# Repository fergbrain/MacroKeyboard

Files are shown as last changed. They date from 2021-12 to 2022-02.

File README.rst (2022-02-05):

.. |ss| raw:: html

    <strike>

.. |se| raw:: html

    </strike>
******
README
******

This is the first successful PCB I've designed. I made it as part of `TeachMePCB's <https://www.teachmepcb.com>`_ PCB Layout 101 class.

Everyone in the course made a macrokeypad of some sort. The core "requirements" were:

* 10 MX-style key switches
* 2 Rotary Encoders with RGB leds
* VEML7700 Ambient Light Sensor (I2C)
* NLSF595 LED Driver (SPI)
* 10 NeoPixel lights (1-wire)
* Don't make a rectangular PCB
* Raspberry Pi Pico microcontroller

I made a couple of changes:

* Swapped PCA9745B for NLSF595
* Added ePaper display (because why not make my first project harder)

Required Libraries
==================
* Standard CircuitPython
* Adafruit CircuitPython Library
    * adafruit_hid
    * adafruit_led_animation
    * adafruit_debouncer
    * adafruit_veml7700
    * adafruit_display_text
    * adafruit_button
* `fergcorp_pca9745b <https://github.com/fergbrain/Fergcorp_CircuitPython_PCA9745B>`_
* `fergcorp_pdispectra <https://github.com/fergbrain/Fergcorp_CircuitPython_PDISpectra>`_

Build Notes and Errata:
=======================
For P/N 21-11.03-3, Rev NEW
---------------------------
**Last updated: 2 Feb 2022**

R1 (c5022a6)
^^^^^^^^^^^^

U401 (PI4ULS5V201TAEX), Pin 6:

* IS: Connected to ground.
* SHOULD BE: Connected to 5V+ via a 4.7K ohm resistor

*Note: All annotations on the PCB were also reset and reassigned. However, the original annotation designations are used in this document.*

R2 (fcf9d7e)
^^^^^^^^^^^^
R2404, Pin 03 (SPI_MISO) of U2701 (PCA9745BTWJ)

* IS: Connected to SPI_MISO via R2704 (1k ohm)
* SHOULD BE: No resistor

Pin 27 (SPI_MOSI) of U2701 (PCA9745BTWJ)

* IS: Connected to SPI_MOSI via R2706 (1k ohm)
* SHOULD BE: No resistor

R2707, Pin 26 (SPI_SCLK) of U2701 (PCA9745BTWJ)

* IS: Connected to SPI_SCLK via R2707 (1k ohm)
* SHOULD BE: No resistor

R3 (bb8617a)
^^^^^^^^^^^^
S3001 (Rotary Encoder)

* IS: Pin 01 (red LED) and Pin 04 (blue LED) are swapped
    * S3001 Pin 01 (red LED) goes to U2701 Pin 13 (blue LED)
    * S3001 Pin 04 (blue LED) goes to U2701 Pin 11 (red LED)

* SHOULD BE:

    * S3001 Pin 01 (red LED) connects to 2701 Pin 11 (red LED)
    * S3001 Pin 04 (blue LED) to U2701 Pin 13 (blue LED)

*Note: This has been fixed in software for this version of the PCB*

R4 (3040ea1)
^^^^^^^^^^^^
J2901 (Connector for epaper) Pin 11 (Data/Command) and Pin 09 (Busy)

* IS:

    * U2801 Pin 15 labeled as GPIO12 and connects to J2901 Pin 11
    * U2801 Pin 16 is labeled as GPIO11 and connects to J2901 Pin 09

* SHOULD BE:

    * U2801 Pin 15 labeled as GPIO11 and connects to Pin 09
    * U2801 Pin 16 labeled as GPIO12 and connects to Pin 11

*Note: This has been fixed in software for this version of the PCB*

R5 (51e2212 / 8b634cf)
^^^^^^^^^^^^
* IS: R2901 is 470 ohms
* SHOULD BE: R2901 is 0.47 ohms

|ss| R6 (196a722) |se|
^^^^^^^^^^^^
* |ss|IS: J2901 (Connector for epaper) Pin 10 (Reset) connected to +3.3V via R2902 (100k ohm)|se|
* |ss|SHOULD BE: J2901 Pin 10 connected to U2801 Pin 14 (GPIO10)|se|
|ss|
*Note: This results in SWITCH 4 and ePaper Reset sharing a pin because there are no other pins available. The primary result is that careful context switching needs to managed in software to:*

1.	Deinitialize GPIO10 as an input for SWITCH 4
2.	Setup the ePaper display interface (which uses GPIO10 as an output)
3.	Perform whatever ePaper update is needed
4.	Deinitialze the ePaper interface (which deinitializes GPIO10 as an output)
5.	Re-initialize GPIO10 as an input for SWITCH 4

*Also, while the ePaper is not enabled (i.e. not initialized/reinitialized), GPIO17 (ePaper CS) needs to be set HIGH to prevent the ePaper controller from thinking that data on the SPI line is intended for it.*
|se|

R7 (80c609b)
^^^^^^^^^^^^
* IS: J2901 is Molex P/N 5052782433
* SHOULD BE: J2901 is Amphenol P/N F31L-1A7H1-11024

* IS: Component S201 and S3001 is SparkFun P/N COM-15141
* SHOULD BE: Bournes P/N PEL12T-4225S-S1024

*Note: COM-15141 was originally sourced as an alternate since the Bournes parts weren’t avaible. However, COM-15141 has quality control issues, including the Red LED not working well and the rotary action not registering correctly. SparkFun is aware of these issues.*

R8 (2cafc4d)
^^^^^^^^^^^^
* IS: J2901 (Connector for epaper) Pin 10 (Reset) connected to +3.3V via R2902 (100k ohm)
* SHOULD BE: J2901 Pin 10 connected to U2801 Pin 48 (GPIO25_LED aka TP5)

*Note: This replaces R6 in its entirety.*

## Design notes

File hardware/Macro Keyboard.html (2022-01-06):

# /Users/andrewferguson/Documents/10-19 Projects/11 Design/11.03 TeachMePCB/Macro Keyboard/Macro Keyboard.sch

Wednesday, December 29, 2021 at 08:03:08 PM

Eeschema (5.1.12-1-10_14)

Component Count:126

Ref | Qnty | Value | Part | Footprint | Description | Vendor
C201, C202, C203, C401, C402, C601, C701, C801, C901, C1001, C1101, C1201, C1301, C1401, C1501, C2701, C2801, C2802, C2901, C2903, C2904, C2905, C2906, C2907, C2908, C2909, C3001, C3002, C3003 | 29 | 1 uF 10% 10V | Device:C_Small | Capacitor_SMD:C_0805_2012Metric_Pad1.18x1.45mm_HandSolder | Unpolarized capacitor, small symbol
C301, C1701, C1801, C1901, C2001, C2101, C2201, C2301, C2401, C2501, C2601 | 11 | 10 uF 10% 10V | Device:C_Small | Capacitor_SMD:C_0805_2012Metric_Pad1.18x1.45mm_HandSolder | Unpolarized capacitor, small symbol
C2902 | 1 | 4.7 uF 10% 10V | Device:C_Small | Capacitor_SMD:C_0805_2012Metric_Pad1.18x1.45mm_HandSolder | Unpolarized capacitor, small symbol
D1701, D1801, D1901, D2001, D2101, D2201, D2301, D2401, D2501, D2601 | 10 | SK6812MINI-E | Macro_Keyboard:SK6812MINI-E | Macro Keyboard:MX_SK6812MINI-E_REV
D2901, D2902, D2903 | 3 | MBR0530 | Device:D_Schottky_Small | Diode_SMD:D_SOD-123 | Schottky diode, small symbol
J2901 | 1 | FPC 1x24 | Macro_Keyboard:Conn_01x24 | Macro Keyboard:Amphenol_F31L-1A7H1-11024 | Generic connector, single row, 01x24, script generated (kicad-library-utils/schlib/autogen/connector/)
L2901 | 1 | 10 uH 20% 0.8A | Device:L_Small | Inductor_SMD:L_Taiyo-Yuden_NR-40xx_HandSoldering | Inductor, small symbol
Q2901 | 1 | Q_PJFET_GDS | Device:Q_PJFET_GDS | Package_TO_SOT_SMD:SOT-23 | P-JFET transistor, gate/drain/source
R201, R203, R207, R301, R302, R601, R701, R801, R901, R1001, R1101, R1201, R1301, R1401, R1501, R2701, R2801, R3001, R3003, R3007 | 20 | 4.7k 5% | Device:R_Small_US | Resistor_SMD:R_0805_2012Metric_Pad1.20x1.40mm_HandSolder | Resistor, small US symbol
R202, R204, R602, R702, R802, R902, R1002, R1102, R1202, R1302, R1402, R1502, R3002, R3004 | 14 | 47k 5% | Device:R_Small_US | Resistor_SMD:R_0805_2012Metric_Pad1.20x1.40mm_HandSolder | Resistor, small US symbol
R205, R1601, R3005 | 3 | 150 5% | Device:R_Small_US | Resistor_SMD:R_0805_2012Metric_Pad1.20x1.40mm_HandSolder | Resistor, small US symbol
R206, R1602, R3006 | 3 | 2.7k 5% | Device:R_Small_US | Resistor_SMD:R_0805_2012Metric_Pad1.20x1.40mm_HandSolder | Resistor, small US symbol
R208, R209, R3008, R3009 | 4 | 68 5% | Device:R_Small_US | Resistor_SMD:R_0805_2012Metric_Pad1.20x1.40mm_HandSolder | Resistor, small US symbol
R2702, R2703, R2704, R2706, R2707 | 5 | 1k 5% | Device:R_Small_US | Resistor_SMD:R_0805_2012Metric_Pad1.20x1.40mm_HandSolder | Resistor, small US symbol
R2705, R2902 | 2 | 100k 5% | Device:R_Small_US | Resistor_SMD:R_0805_2012Metric_Pad1.20x1.40mm_HandSolder | Resistor, small US symbol
R2901 | 1 | 470 5% | Device:R_Small_US | Resistor_SMD:R_0805_2012Metric_Pad1.20x1.40mm_HandSolder | Resistor, small US symbol
S201, S3001 | 2 | ENCODER-RGB-SWITCH | TMPCB_R2:ENCODER-RGB-SWITCH | ENCODER_LED_3
SW601, SW701, SW801, SW901, SW1001, SW1101, SW1201, SW1301, SW1401, SW1501 | 10 | KH-PS1611-54 | Switch:SW_Push | TMPPCB_R2:SW_MX | Push button switch, generic, two pins
SW2801 | 1 | SWITCH TACTILE SPST-NO 50MA 12V | Switch:SW_Push | Button_Switch_SMD:SW_SPST_TL3305A | Push button switch, generic, two pins
U301 | 1 | VEML7700 | TMPCB_R2:VEML7700 | TMPPCB_R2:SMD4-X07Y16P127
U401 | 1 | PI4ULS5V201TAEX | TMPCB_R2:PI4ULS5V201TAEX | Package_TO_SOT_SMD:SOT-23-6
U2701 | 1 | PCA9745BTWJ | Macro_Keyboard:PCA9745BTWJ | Macro Keyboard:PCA9745BTWJ
U2801 | 1 | Pico-JER | TMPCB_R2:Pico-JER | TMPPCB_R2:RPi_Pico_SMD_TH-JER

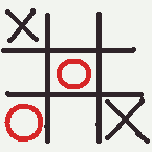
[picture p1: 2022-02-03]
tictactoe.bmp

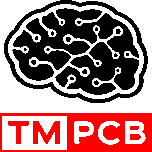
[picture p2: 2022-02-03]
tmpcb.bmp

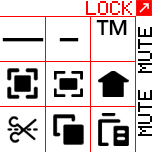
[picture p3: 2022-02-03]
macrokeyboard.bmp

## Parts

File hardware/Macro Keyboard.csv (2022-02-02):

Item | Qty | Reference(s) | Value | Digikey PN | MFG | MFG # | Notes
1 | 29 | C201, C202, C203, C401, C402, C601, C701, C801, C901, C1001, C1101, C1201, C1301, C1401, C1501, C2701, C2801, C2802, C2901, C2903, C2904, C2905, C2906, C2907, C2908, C2909, C3001, C3002, C3003 | 1 uF 10% 10V | 1276-1275-1-ND | Samsung Electro-Mechanics | CL21B105KPFNNNE
2 | 11 | C301, C1701, C1801, C1901, C2001, C2101, C2201, C2301, C2401, C2501, C2601 | 10 uF 10% 10V | 1276-2402-1-ND | Samsung Electro-Mechanics | CL21A106KPCLQNC
3 | 1 | C2902 | 4.7 uF 10% 10V | 1276-1259-1-ND | Samsung Electro-Mechanics | CL21A475KPFNNNE
4 | 10 | D1701, D1801, D1901, D2001, D2101, D2201, D2301, D2401, D2501, D2601 | SK6812MINI-E | 1528-4960-ND | Adafruit Industries LLC | 4960 | Comes in pack of 10
5 | 3 | D2901, D2902, D2903 | MBR0530 | MBR0530TPMSCT-ND | Micro Commercial Co | MBR0530-TP
6 | 1 | J2901 | FPC 1x24 | WM20872CT-ND | Molex | 5052782433
7 | 1 | L2901 | 10 uH 20% 0.8A | 587-1659-1-ND | Taiyo Yuden | NR4012T100M
8 | 1 | Q2901 | Q_PJFET_GDS | TSM850N06CXRFGCT-ND | Taiwan Semiconductor Corporation | TSM850N06CX RFG
9 | 20 | R201, R203, R207, R301, R302, R601, R701, R801, R901, R1001, R1101, R1201, R1301, R1401, R1501, R2701, R2801, R3001, R3003, R3007 | 4.7k 5% | RMCF0805JT4K70CT-ND | Stackpole Electronics Inc | RMCF0805JT4K70
10 | 14 | R202, R204, R602, R702, R802, R902, R1002, R1102, R1202, R1302, R1402, R1502, R3002, R3004 | 47k 5% | RMCF0805JT47K0CT-ND | Stackpole Electronics Inc | RMCF0805JT47K0
11 | 3 | R205, R1601, R3005 | 150 5% | RMCF0805JT150RCT-ND | Stackpole Electronics Inc | RMCF0805JT150R
12 | 3 | R206, R1602, R3006 | 2.7k 5% | RMCF0805JT2K70CT-ND | Stackpole Electronics Inc | RMCF0805JT2K70
13 | 4 | R208, R209, R3008, R3009 | 68 5% | RMCF0805JT68R0CT-ND | Stackpole Electronics Inc | RMCF0805JT68R0
14 | 5 | R2702, R2703, R2704, R2706, R2707 | 1k 5% | RMCF0805JT1K00CT-ND | Stackpole Electronics Inc | RMCF0805JT1K00
15 | 2 | R2705, R2902 | 100k 5% | RMCF0805JT100KCT-ND | Stackpole Electronics Inc | RMCF0805JT100K
16 | 1 | R2901 | 470 5% | RMCF0805JT470RCT-ND | Stackpole Electronics Inc | RMCF0805JT470R
17 | 2 | S201, S3001 | ENCODER-RGB- SWITCH | 1568-COM-15141-ND | SparkFun Electronics | COM-15141 | Ordered from Spark Fun directly
18 | 10 | SW601, SW701, SW801, SW901, SW1001, SW1101, SW1201, SW1301, SW1401, SW1501 | KH-PS1611-54 | 1528-495ND | Adafruit Industries LLC | 4955 | Comes in pack of 10
19 | 1 | SW2801 | SWITCH TACTILE SPST-NO 50MA 12V | EG5353CT-ND | E-Switch | TL3305AF260QG
20 | 1 | U301 | VEML7700 | VEML7700CT-ND | Vishay Semiconductor | VEML7700-TR
21 | 1 | U401 | PI4ULS5V201TAEX | PI4ULS5V201TAEXCT-ND | Diodes Inc | PI4ULS5V201TAEX
22 | 1 | U2701 | PCA9745BTWJ | 568-14156-1-ND | NXP USA Inc. | PCA9745BTWJ
23 | 1 | U2801 | Pico-JER | 2648-SC0915CT-ND | Raspberry Pi | SC0915
Source: |  |  | /Users/andrewferguson/Documents/10-19 Projects/11 Design/11.03 TeachMePCB/Macro Keyboard/Macro Keyboard.sch
Date: |  |  | Wednesday, December 29, 2021 at 08:10:08 PM
Tool: |  |  | Eeschema (5.1.12-1-10_14)
Generator: |  |  | /Applications/KiCad/kicad.app/Contents/SharedSupport/plugins/bom_csv_grouped_by_value.py
Component Count: |  |  | 126

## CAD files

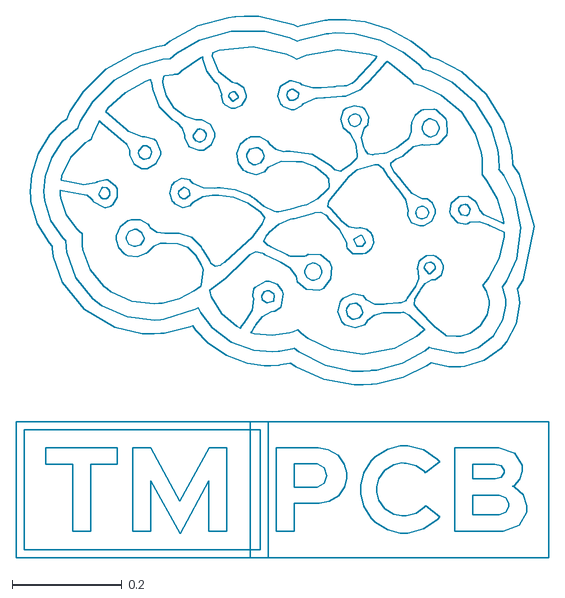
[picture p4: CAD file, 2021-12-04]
hardware/Asset 1.dxf
0.969 x 0.986

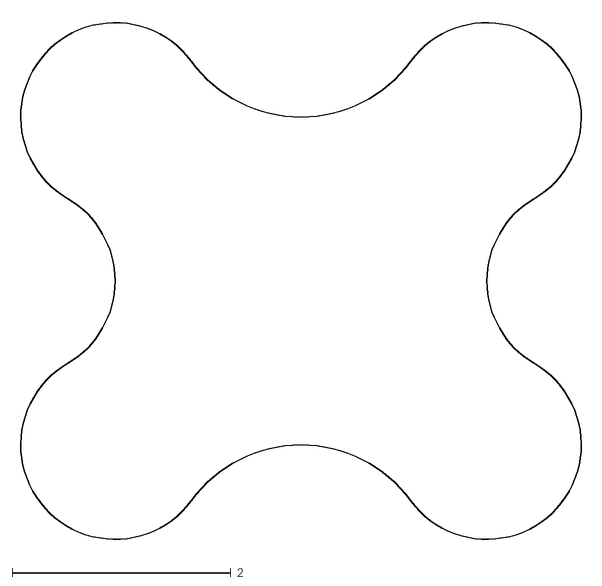
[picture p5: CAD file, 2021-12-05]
hardware/outline/SK6812E-Sketch.dxf
5.21 x 4.85

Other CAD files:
hardware/outline/SK6812E.FCStd
hardware/outline/Outline.FCStd
hardware/Asset-1.dxf
hardware/outline/Outline.dxf

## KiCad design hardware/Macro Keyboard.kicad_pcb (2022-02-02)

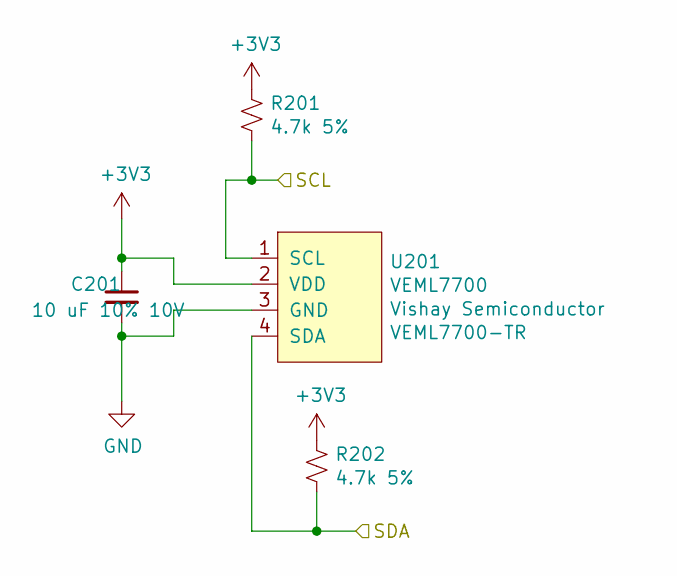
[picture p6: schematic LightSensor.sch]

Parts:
C201: 10 uF 10% 10V; C_0805_2012Metric_Pad1.18x1.45mm_HandSolder; MFG # CL21A106KPCLQNC; Digikey PN 1276-2402-1-ND
R201, R202: 4.7k 5%; R_0805_2012Metric_Pad1.20x1.40mm_HandSolder; MFG # RMCF0805JT4K70; Digikey PN RMCF0805JT4K70CT-ND
U201: VEML7700; SMD4-X07Y16P127; MFG # VEML7700-TR; Digikey PN VEML7700CT-ND

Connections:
+3V3: C201.1, R201.1, R202.1, U201.2 (VDD); also elsewhere on the board
/SCL: R201.2, U201.1 (SCL); also elsewhere on the board
/SDA: R202.2, U201.4 (SDA); also elsewhere on the board
GND: C201.2, U201.3 (GND); also elsewhere on the board

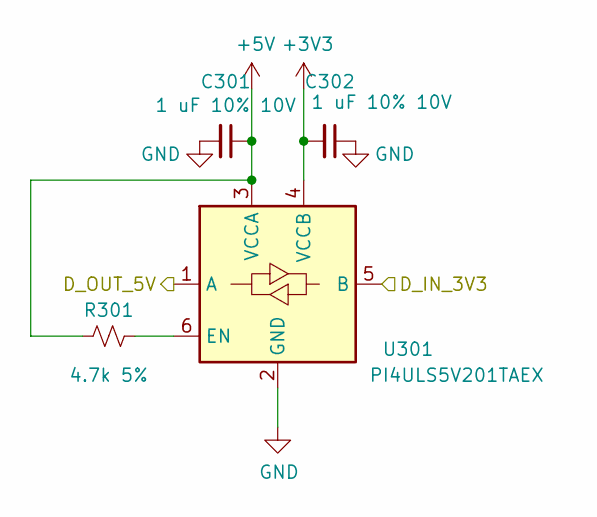
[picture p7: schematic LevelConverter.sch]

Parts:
C301, C302: 1 uF 10% 10V; C_0805_2012Metric_Pad1.18x1.45mm_HandSolder; MFG # CL21B105KPFNNNE; Digikey PN 1276-1275-1-ND
R301: 4.7k 5%; R_0805_2012Metric_Pad1.20x1.40mm_HandSolder
U301: PI4ULS5V201TAEX; SOT-23-6; MFG # PI4ULS5V201TAEX; Digikey PN PI4ULS5V201TAEXCT-ND

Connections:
+3V3: C302.2, U301.4 (VCCB); also elsewhere on the board
+5V: C301.1, R301.2, U301.3 (VCCA); also elsewhere on the board
/D_IN_3V3: U301.5 (B); also elsewhere on the board
/Level Converter/D_OUT_5V: U301.1 (A); also elsewhere on the board
GND: C301.2, C302.1, U301.2 (GND); also elsewhere on the board
unnamed: R301.1, U301.6 (EN)

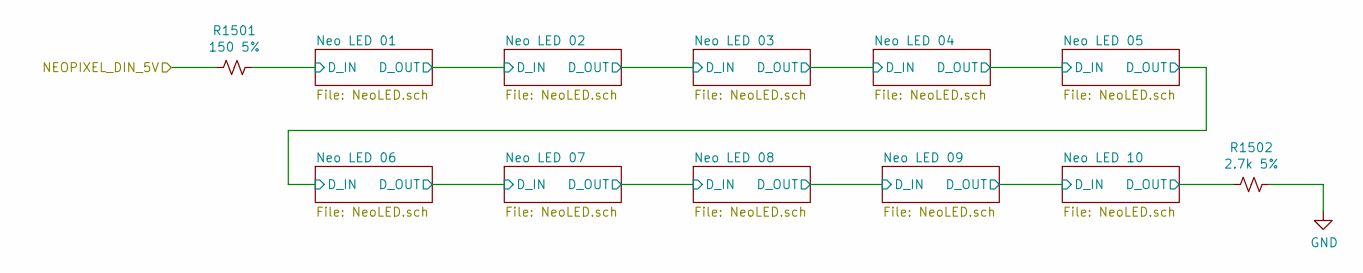
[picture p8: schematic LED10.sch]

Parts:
R1501: 150 5%; R_0805_2012Metric_Pad1.20x1.40mm_HandSolder; MFG # RMCF0805JT150R; Digikey PN RMCF0805JT150RCT-ND
R1502: 2.7k 5%; R_0805_2012Metric_Pad1.20x1.40mm_HandSolder; MFG # RMCF0805JT2K70; Digikey PN RMCF0805JT2K70CT-ND

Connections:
/LED 10/Neo LED 01/D_IN: R1501.1; also elsewhere on the board
/LED 10/Neo LED 10/D_OUT: R1502.2; also elsewhere on the board
/Level Converter/D_OUT_5V: R1501.2; also elsewhere on the board
GND: R1502.1; also elsewhere on the board

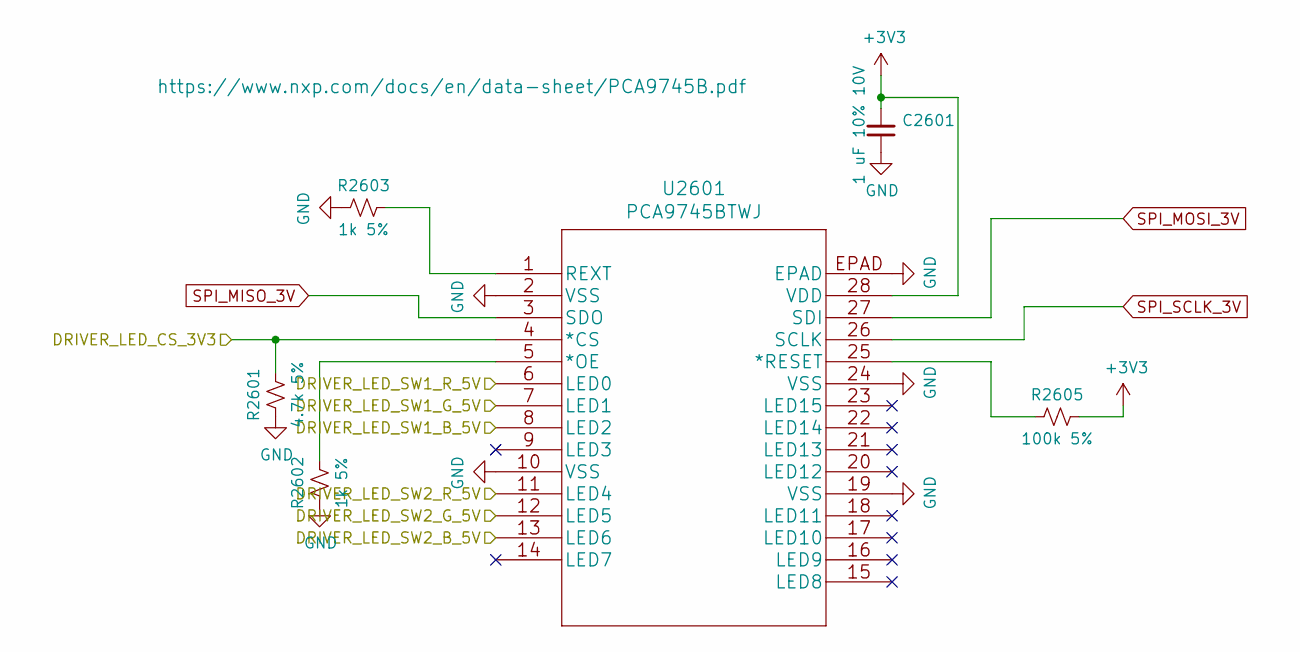
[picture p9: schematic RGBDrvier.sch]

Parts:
C2601: 1 uF 10% 10V; C_0805_2012Metric_Pad1.18x1.45mm_HandSolder; MFG # CL21B105KPFNNNE; Digikey PN 1276-1275-1-ND
R2601: 4.7k 5%; R_0805_2012Metric_Pad1.20x1.40mm_HandSolder; MFG # RMCF0805JT4K70; Digikey PN RMCF0805JT4K70CT-ND
R2602, R2603: 1k 5%; R_0805_2012Metric_Pad1.20x1.40mm_HandSolder; MFG # RMCF0805JT1K00; Digikey PN RMCF0805JT1K00CT-ND
R2605: 100k 5%; R_0805_2012Metric_Pad1.20x1.40mm_HandSolder; MFG # RMCF0805JT100K; Digikey PN RMCF0805JT100KCT-ND
U2601: PCA9745BTWJ; MFG # PCA9745BTWJ; Digikey PN 568-14156-1-ND

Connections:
+3V3: C2601.2, R2605.1, U2601.28 (VDD); also elsewhere on the board
/DRIVER_LED_CS: R2601.2, U2601.4 (*CS); also elsewhere on the board
/RGB Driver/DRIVER_LED_SW1_B_5V: U2601.8 (LED2); also elsewhere on the board
/RGB Driver/DRIVER_LED_SW1_G_5V: U2601.7 (LED1); also elsewhere on the board
/RGB Driver/DRIVER_LED_SW1_R_5V: U2601.6 (LED0); also elsewhere on the board
/RGB Driver/DRIVER_LED_SW2_B_5V: U2601.13 (LED6); also elsewhere on the board
/RGB Driver/DRIVER_LED_SW2_G_5V: U2601.12 (LED5); also elsewhere on the board
/RGB Driver/DRIVER_LED_SW2_R_5V: U2601.11 (LED4); also elsewhere on the board
GND: C2601.1, R2601.1, R2602.1, R2603.2, U2601.2 (VSS), U2601.10 (VSS), U2601.19 (VSS), U2601.24 (VSS), U2601.EPAD; also elsewhere on the board
unnamed: R2602.2, U2601.5 (*OE)
unnamed: R2603.1, U2601.1 (REXT)
unnamed: R2605.2, U2601.25 (*RESET)
SPI_MISO_3V: U2601.3 (SDO); also elsewhere on the board
SPI_MOSI_3V: U2601.27 (SDI); also elsewhere on the board
SPI_SCLK_3V: U2601.26 (SCLK); also elsewhere on the board

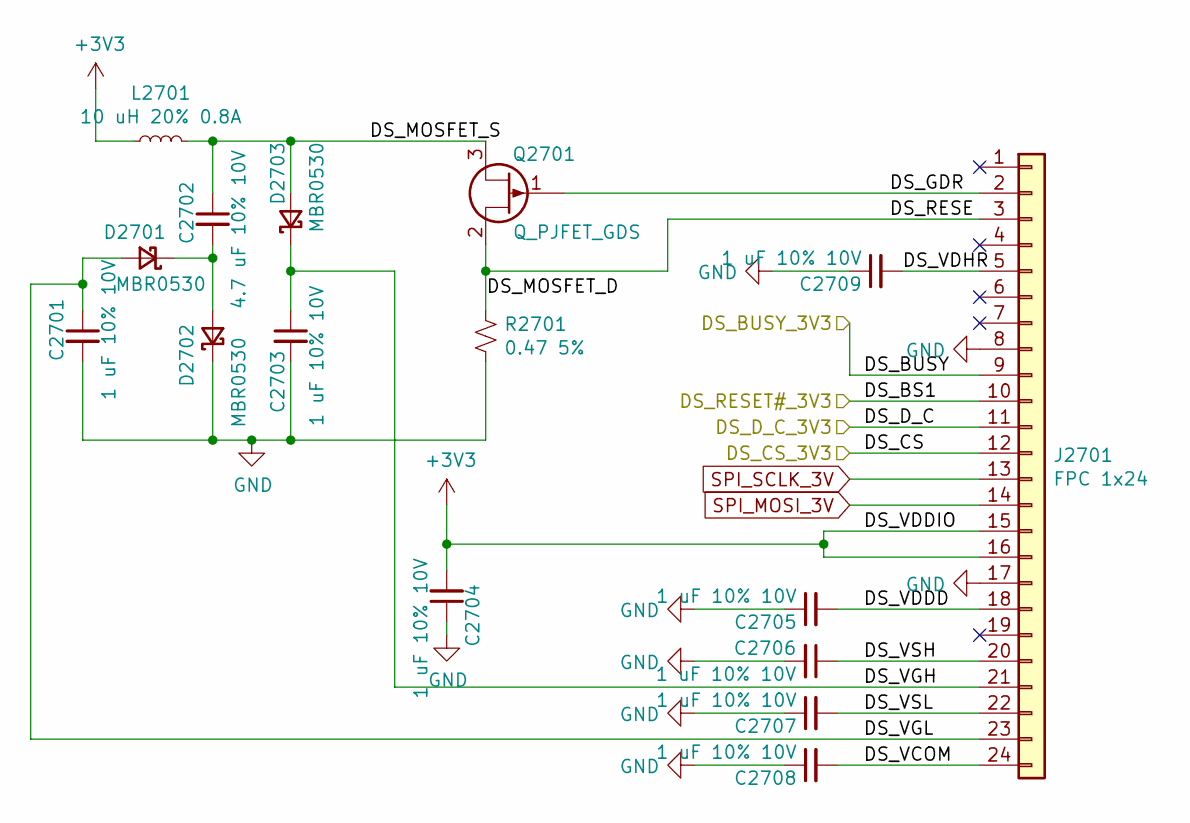
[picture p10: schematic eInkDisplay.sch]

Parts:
C2701, C2703, C2704, C2705, C2706, C2707, C2708, C2709: 1 uF 10% 10V; C_0805_2012Metric_Pad1.18x1.45mm_HandSolder; MFG # CL21B105KPFNNNE; Digikey PN 1276-1275-1-ND
C2702: 4.7 uF 10% 10V; C_0805_2012Metric_Pad1.18x1.45mm_HandSolder; MFG # CL21A475KPFNNNE; Digikey PN 1276-1259-1-ND
D2701, D2702, D2703: MBR0530; D_SOD-123; MFG # MBR0530-TP; Digikey PN MBR0530TPMSCT-ND
J2701: FPC 1x24; Amphenol_F31L-1A7H1-11024; MFG # F31L-1A7H1-11024; Digikey PN 609-F31L-1A7H1-11024CT-ND
L2701: 10 uH 20% 0.8A; L_Taiyo-Yuden_NR-40xx_HandSoldering; MFG # NR4012T100M; Digikey PN 587-1659-1-ND
Q2701: Q_PJFET_GDS; SOT-23; MFG # TSM850N06CX RFG; Digikey PN TSM850N06CXRFGCT-ND
R2701: 0.47 5%; R_0805_2012Metric_Pad1.20x1.40mm_HandSolder; MFG # RMCF0805JT470R; Digikey PN RMCF0805JT470RCT-ND

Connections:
+3V3: C2704.2, J2701.15, J2701.16, L2701.1; also elsewhere on the board
/DS_BUSY_3V3: J2701.9; also elsewhere on the board
/DS_CS_3V3: J2701.12; also elsewhere on the board
/DS_D_C_3V3: J2701.11; also elsewhere on the board
/eInk Display/DS_GDR: J2701.2, Q2701.1 (G)
/eInk Display/DS_MOSFET_D: J2701.3, Q2701.2 (D), R2701.1
/eInk Display/DS_MOSFET_S: C2702.1, D2703.2 (A), L2701.2, Q2701.3 (S)
/eInk Display/DS_RESET#_3V3: J2701.10; also elsewhere on the board
/eInk Display/DS_VCOM: C2708.2, J2701.24
/eInk Display/DS_VDDD: C2705.2, J2701.18
/eInk Display/DS_VDHR: C2709.2, J2701.5
/eInk Display/DS_VGH: C2703.1, D2703.1 (K), J2701.21
/eInk Display/DS_VGL: C2701.1, D2701.2 (A), J2701.23
/eInk Display/DS_VSH: C2706.1, J2701.20
/eInk Display/DS_VSL: C2707.2, J2701.22
GND: C2701.2, C2703.2, C2704.1, C2705.1, C2706.2, C2707.1, C2708.1, C2709.1, D2702.1 (K), J2701.8, J2701.17, R2701.2; also elsewhere on the board
unnamed: C2702.2, D2701.1 (K), D2702.2 (A)
SPI_MOSI_3V: J2701.14; also elsewhere on the board
SPI_SCLK_3V: J2701.13; also elsewhere on the board

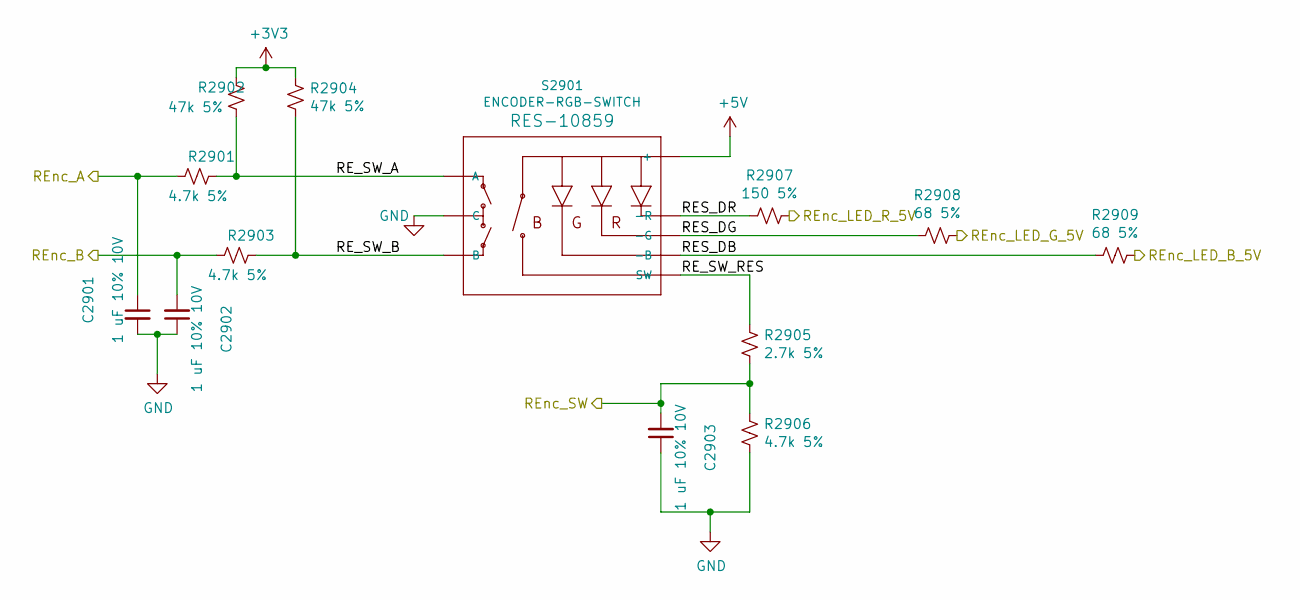
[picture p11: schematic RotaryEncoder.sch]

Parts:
C2901, C2902, C2903: 1 uF 10% 10V; C_0805_2012Metric_Pad1.18x1.45mm_HandSolder; MFG # CL21B105KPFNNNE; Digikey PN 1276-1275-1-ND
R2901, R2903, R2906: 4.7k 5%; R_0805_2012Metric_Pad1.20x1.40mm_HandSolder; MFG # RMCF0805JT4K70; Digikey PN RMCF0805JT4K70CT-ND
R2902, R2904: 47k 5%; R_0805_2012Metric_Pad1.20x1.40mm_HandSolder; MFG # RMCF0805JT47K0; Digikey PN RMCF0805JT47K0CT-ND
R2905: 2.7k 5%; R_0805_2012Metric_Pad1.20x1.40mm_HandSolder; MFG # RMCF0805JT2K70; Digikey PN RMCF0805JT2K70CT-ND
R2907: 150 5%; R_0805_2012Metric_Pad1.20x1.40mm_HandSolder; MFG # RMCF0805JT150R; Digikey PN RMCF0805JT150RCT-ND
R2908, R2909: 68 5%; R_0805_2012Metric_Pad1.20x1.40mm_HandSolder; MFG # RMCF0805JT68R0; Digikey PN RMCF0805JT68R0CT-ND
S2901: ENCODER-RGB-SWITCH; ENCODER_LED_3; MFG # PEL12T-4225S-S1024; Digikey PN PEL12T-4225S-S1024-ND

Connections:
+3V3: R2902.2, R2904.2; also elsewhere on the board
+5V: S2901.5 (+); also elsewhere on the board
/REnc_1_A: C2901.1, R2901.1; also elsewhere on the board
/REnc_1_B: C2902.2, R2903.1; also elsewhere on the board
/REnc_1_SW: C2903.2, R2905.1, R2906.2; also elsewhere on the board
/RGB Driver/DRIVER_LED_SW1_B_5V: R2909.1; also elsewhere on the board
/RGB Driver/DRIVER_LED_SW1_G_5V: R2908.1; also elsewhere on the board
/RGB Driver/DRIVER_LED_SW1_R_5V: R2907.1; also elsewhere on the board
/Rotary Encoder 1/RES_DB: R2909.2, S2901.4 (-B)
/Rotary Encoder 1/RES_DG: R2908.2, S2901.2 (-G)
/Rotary Encoder 1/RES_DR: R2907.2, S2901.1 (-R)
/Rotary Encoder 1/RE_SW_A: R2901.2, R2902.1, S2901.A
/Rotary Encoder 1/RE_SW_B: R2903.2, R2904.1, S2901.B
/Rotary Encoder 1/RE_SW_RES: R2905.2, S2901.3 (SW)
GND: C2901.2, C2902.1, C2903.1, R2906.1, S2901.C; also elsewhere on the board

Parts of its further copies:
C2801, C2802, C2803: 1 uF 10% 10V; C_0805_2012Metric_Pad1.18x1.45mm_HandSolder; MFG # CL21B105KPFNNNE; Digikey PN 1276-1275-1-ND
R2801, R2803, R2806: 4.7k 5%; R_0805_2012Metric_Pad1.20x1.40mm_HandSolder; MFG # RMCF0805JT4K70; Digikey PN RMCF0805JT4K70CT-ND
R2802, R2804: 47k 5%; R_0805_2012Metric_Pad1.20x1.40mm_HandSolder; MFG # RMCF0805JT47K0; Digikey PN RMCF0805JT47K0CT-ND
R2805: 2.7k 5%; R_0805_2012Metric_Pad1.20x1.40mm_HandSolder; MFG # RMCF0805JT2K70; Digikey PN RMCF0805JT2K70CT-ND
R2807: 150 5%; R_0805_2012Metric_Pad1.20x1.40mm_HandSolder; MFG # RMCF0805JT150R; Digikey PN RMCF0805JT150RCT-ND
R2808, R2809: 68 5%; R_0805_2012Metric_Pad1.20x1.40mm_HandSolder; MFG # RMCF0805JT68R0; Digikey PN RMCF0805JT68R0CT-ND
S2801: ENCODER-RGB-SWITCH; ENCODER_LED_3; MFG # PEL12T-4225S-S1024; Digikey PN PEL12T-4225S-S1024-ND

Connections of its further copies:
+3V3: R2802.2, R2804.2; also elsewhere on the board
+5V: S2801.5 (+); also elsewhere on the board
/REnc_2_A: C2801.1, R2801.1; also elsewhere on the board
/REnc_2_B: C2802.2, R2803.1; also elsewhere on the board
/REnc_2_SW: C2803.2, R2805.1, R2806.2; also elsewhere on the board
/RGB Driver/DRIVER_LED_SW2_B_5V: R2809.1; also elsewhere on the board
/RGB Driver/DRIVER_LED_SW2_G_5V: R2808.1; also elsewhere on the board
/RGB Driver/DRIVER_LED_SW2_R_5V: R2807.1; also elsewhere on the board
/Rotary Encoder 2/RES_DB: R2809.2, S2801.4 (-B)
/Rotary Encoder 2/RES_DG: R2808.2, S2801.2 (-G)
/Rotary Encoder 2/RES_DR: R2807.2, S2801.1 (-R)
/Rotary Encoder 2/RE_SW_A: R2801.2, R2802.1, S2801.A
/Rotary Encoder 2/RE_SW_B: R2803.2, R2804.1, S2801.B
/Rotary Encoder 2/RE_SW_RES: R2805.2, S2801.3 (SW)
GND: C2801.2, C2802.1, C2803.1, R2806.1, S2801.C; also elsewhere on the board

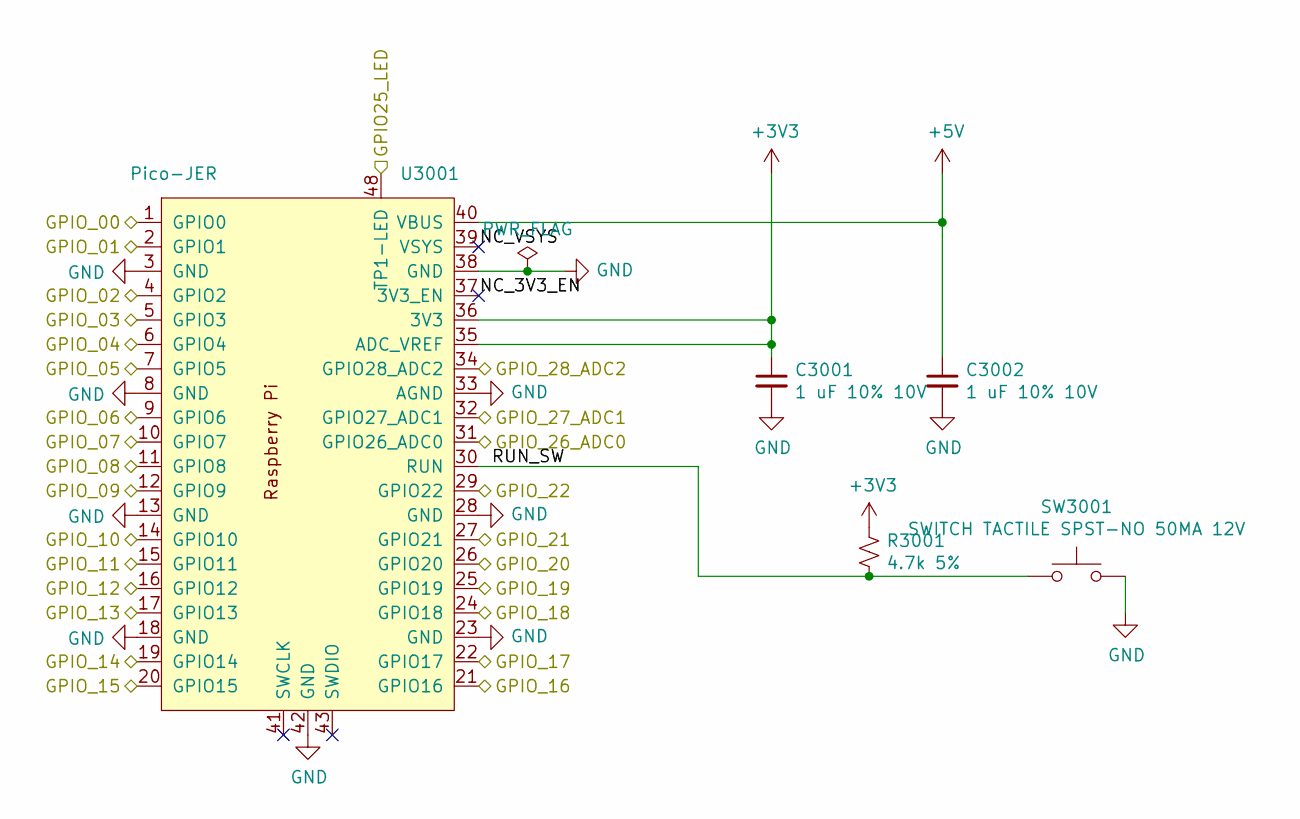
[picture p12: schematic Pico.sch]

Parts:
C3001, C3002: 1 uF 10% 10V; C_0805_2012Metric_Pad1.18x1.45mm_HandSolder; MFG # CL21B105KPFNNNE; Digikey PN 1276-1275-1-ND
R3001: 4.7k 5%; R_0805_2012Metric_Pad1.20x1.40mm_HandSolder; MFG # RMCF0805JT4K70; Digikey PN RMCF0805JT4K70CT-ND
SW3001: SWITCH TACTILE SPST-NO 50MA 12V; SW_SPST_TL3305A; MFG # TL3305AF260QG; Digikey PN EG5353CT-ND
U3001: Pico-JER; RPi_Pico_SMD_TH-JER; MFG # SC0915; Digikey PN 2648-SC0915CT-ND

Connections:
+3V3: C3001.1, R3001.1, U3001.35 (ADC_VREF), U3001.36 (3V3); also elsewhere on the board
+5V: C3002.1, U3001.40 (VBUS); also elsewhere on the board
/DRIVER_LED_CS: U3001.17 (GPIO13); also elsewhere on the board
/DS_BUSY_3V3: U3001.16 (GPIO12); also elsewhere on the board
/DS_CS_3V3: U3001.22 (GPIO17); also elsewhere on the board
/DS_D_C_3V3: U3001.15 (GPIO11); also elsewhere on the board
/D_IN_3V3: U3001.1 (GPIO0); also elsewhere on the board
/Pico/NC_3V3_EN: U3001.37 (3V3_EN)
/Pico/NC_VSYS: U3001.39 (VSYS)
/Pico/RUN_SW: R3001.2, SW3001.1, U3001.30 (RUN)
/REnc_1_A: U3001.19 (GPIO14); also elsewhere on the board
/REnc_1_B: U3001.20 (GPIO15); also elsewhere on the board
/REnc_1_SW: U3001.29 (GPIO22); also elsewhere on the board
/REnc_2_A: U3001.34 (GPIO28_ADC2); also elsewhere on the board
/REnc_2_B: U3001.32 (GPIO27_ADC1); also elsewhere on the board
/REnc_2_SW: U3001.31 (GPIO26_ADC0); also elsewhere on the board
/SCL: U3001.27 (GPIO21); also elsewhere on the board
/SDA: U3001.26 (GPIO20); also elsewhere on the board
/SW1: U3001.2 (GPIO1); also elsewhere on the board
/SW2: U3001.4 (GPIO2); also elsewhere on the board
/SW3: U3001.10 (GPIO7); also elsewhere on the board
/SW4: U3001.14 (GPIO10); also elsewhere on the board
/SW5: U3001.12 (GPIO9); also elsewhere on the board
/SW6: U3001.9 (GPIO6); also elsewhere on the board
/SW7: U3001.5 (GPIO3); also elsewhere on the board
/SW8: U3001.6 (GPIO4); also elsewhere on the board
/SW9: U3001.7 (GPIO5); also elsewhere on the board
/SW10: U3001.11 (GPIO8); also elsewhere on the board
/eInk Display/DS_RESET#_3V3: U3001.48 (TP1-LED); also elsewhere on the board
GND: C3001.2, C3002.2, SW3001.2, U3001.3 (GND), U3001.8 (GND), U3001.13 (GND), U3001.18 (GND), U3001.23 (GND), U3001.28 (GND), U3001.33 (AGND), U3001.38 (GND), U3001.42 (GND); also elsewhere on the board
SPI_MISO_3V: U3001.21 (GPIO16); also elsewhere on the board
SPI_MOSI_3V: U3001.25 (GPIO19); also elsewhere on the board
SPI_SCLK_3V: U3001.24 (GPIO18); also elsewhere on the board

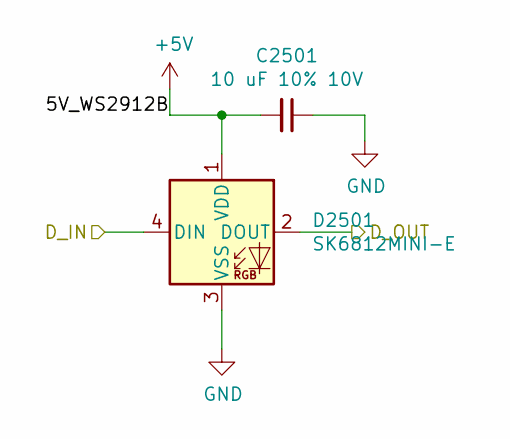
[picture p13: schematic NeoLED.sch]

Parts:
C1601: 10 uF 10% 10V; C_0805_2012Metric_Pad1.18x1.45mm_HandSolder; MFG # CL21A106KPCLQNC; Digikey PN 1276-2402-1-ND
D1601: SK6812MINI-E; MX_SK6812MINI-E_REV; MFG # 4960; Digikey PN 1528-4960-ND

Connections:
+5V: C1601.2, D1601.1 (VDD); also elsewhere on the board
/LED 10/Neo LED 01/D_IN: D1601.4 (DIN); also elsewhere on the board
/LED 10/Neo LED 02/D_IN: D1601.2 (DOUT); also elsewhere on the board
GND: C1601.1, D1601.3 (VSS); also elsewhere on the board

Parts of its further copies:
C1701, C1801, C1901, C2001, C2101, C2201, C2301, C2401, C2501: 10 uF 10% 10V; C_0805_2012Metric_Pad1.18x1.45mm_HandSolder; MFG # CL21A106KPCLQNC; Digikey PN 1276-2402-1-ND
D1701, D1801, D1901, D2001, D2101, D2201, D2301, D2401, D2501: SK6812MINI-E; MX_SK6812MINI-E_REV; MFG # 4960; Digikey PN 1528-4960-ND

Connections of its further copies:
+5V: C1701.2, C1801.2, C1901.2, C2001.2, C2101.2, C2201.2, C2301.2, C2401.2, C2501.2, D1701.1 (VDD), D1801.1 (VDD), D1901.1 (VDD), D2001.1 (VDD), D2101.1 (VDD), D2201.1 (VDD), D2301.1 (VDD), D2401.1 (VDD), D2501.1 (VDD); also elsewhere on the board
/LED 10/Neo LED 02/D_IN: D1701.4 (DIN); also elsewhere on the board
/LED 10/Neo LED 03/D_IN: D1701.2 (DOUT), D1801.4 (DIN)
/LED 10/Neo LED 04/D_IN: D1801.2 (DOUT), D1901.4 (DIN)
/LED 10/Neo LED 05/D_IN: D1901.2 (DOUT), D2001.4 (DIN)
/LED 10/Neo LED 06/D_IN: D2001.2 (DOUT), D2101.4 (DIN)
/LED 10/Neo LED 07/D_IN: D2101.2 (DOUT), D2201.4 (DIN)
/LED 10/Neo LED 08/D_IN: D2201.2 (DOUT), D2301.4 (DIN)
/LED 10/Neo LED 09/D_IN: D2301.2 (DOUT), D2401.4 (DIN)
/LED 10/Neo LED 10/D_IN: D2401.2 (DOUT), D2501.4 (DIN)
/LED 10/Neo LED 10/D_OUT: D2501.2 (DOUT); also elsewhere on the board
GND: C1701.1, C1801.1, C1901.1, C2001.1, C2101.1, C2201.1, C2301.1, C2401.1, C2501.1, D1701.3 (VSS), D1801.3 (VSS), D1901.3 (VSS), D2001.3 (VSS), D2101.3 (VSS), D2201.3 (VSS), D2301.3 (VSS), D2401.3 (VSS), D2501.3 (VSS); also elsewhere on the board

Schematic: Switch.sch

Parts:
C501: 1 uF 10% 10V; C_0805_2012Metric_Pad1.18x1.45mm_HandSolder; MFG # CL21B105KPFNNNE; Digikey PN 1276-1275-1-ND
R501: 4.7k 5%; R_0805_2012Metric_Pad1.20x1.40mm_HandSolder; MFG # RMCF0805JT4K70; Digikey PN RMCF0805JT4K70CT-ND
R502: 47k 5%; R_0805_2012Metric_Pad1.20x1.40mm_HandSolder; MFG # RMCF0805JT47K0; Digikey PN RMCF0805JT47K0CT-ND
SW501: KH-PS1611-54; SW_MX; MFG # 4955; Digikey PN 1528-495ND

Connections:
+3V3: R502.1; also elsewhere on the board
/10 Group Switch/Switch_1/SW_RDIV: R501.1, R502.2, SW501.1
/SW1: C501.1, R501.2; also elsewhere on the board
GND: C501.2, SW501.2; also elsewhere on the board

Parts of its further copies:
C601, C701, C801, C901, C1001, C1101, C1201, C1301, C1401: 1 uF 10% 10V; C_0805_2012Metric_Pad1.18x1.45mm_HandSolder; MFG # CL21B105KPFNNNE; Digikey PN 1276-1275-1-ND
R601, R701, R801, R901, R1001, R1101, R1201, R1301, R1401: 4.7k 5%; R_0805_2012Metric_Pad1.20x1.40mm_HandSolder; MFG # RMCF0805JT4K70; Digikey PN RMCF0805JT4K70CT-ND
R602, R702, R802, R902, R1002, R1102, R1202, R1302, R1402: 47k 5%; R_0805_2012Metric_Pad1.20x1.40mm_HandSolder; MFG # RMCF0805JT47K0; Digikey PN RMCF0805JT47K0CT-ND
SW601, SW701, SW801, SW901, SW1001, SW1101, SW1201, SW1301, SW1401: KH-PS1611-54; SW_MX; MFG # 4955; Digikey PN 1528-495ND

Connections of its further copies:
+3V3: R602.1, R702.1, R802.1, R902.1, R1002.1, R1102.1, R1202.1, R1302.1, R1402.1; also elsewhere on the board
/10 Group Switch/Switch 2/SW_RDIV: R601.1, R602.2, SW601.1
/10 Group Switch/Switch 3/SW_RDIV: R701.1, R702.2, SW701.1
/10 Group Switch/Switch 4/SW_RDIV: R801.1, R802.2, SW801.1
/10 Group Switch/Switch 5/SW_RDIV: R901.1, R902.2, SW901.1
/10 Group Switch/Switch 6/SW_RDIV: R1001.1, R1002.2, SW1001.1
/10 Group Switch/Switch 7/SW_RDIV: R1101.1, R1102.2, SW1101.1
/10 Group Switch/Switch 8/SW_RDIV: R1201.1, R1202.2, SW1201.1
/10 Group Switch/Switch 9/SW_RDIV: R1301.1, R1302.2, SW1301.1
/10 Group Switch/Switch 10/SW_RDIV: R1401.1, R1402.2, SW1401.1
/SW2: C601.1, R601.2; also elsewhere on the board
/SW3: C701.1, R701.2; also elsewhere on the board
/SW4: C801.1, R801.2; also elsewhere on the board
/SW5: C901.1, R901.2; also elsewhere on the board
/SW6: C1001.1, R1001.2; also elsewhere on the board
/SW7: C1101.1, R1101.2; also elsewhere on the board
/SW8: C1201.1, R1201.2; also elsewhere on the board
/SW9: C1301.1, R1301.2; also elsewhere on the board
/SW10: C1401.1, R1401.2; also elsewhere on the board
GND: C601.2, C701.2, C801.2, C901.2, C1001.2, C1101.2, C1201.2, C1301.2, C1401.2, SW601.2, SW701.2, SW801.2, SW901.2, SW1001.2, SW1101.2, SW1201.2, SW1301.2, SW1401.2; also elsewhere on the board

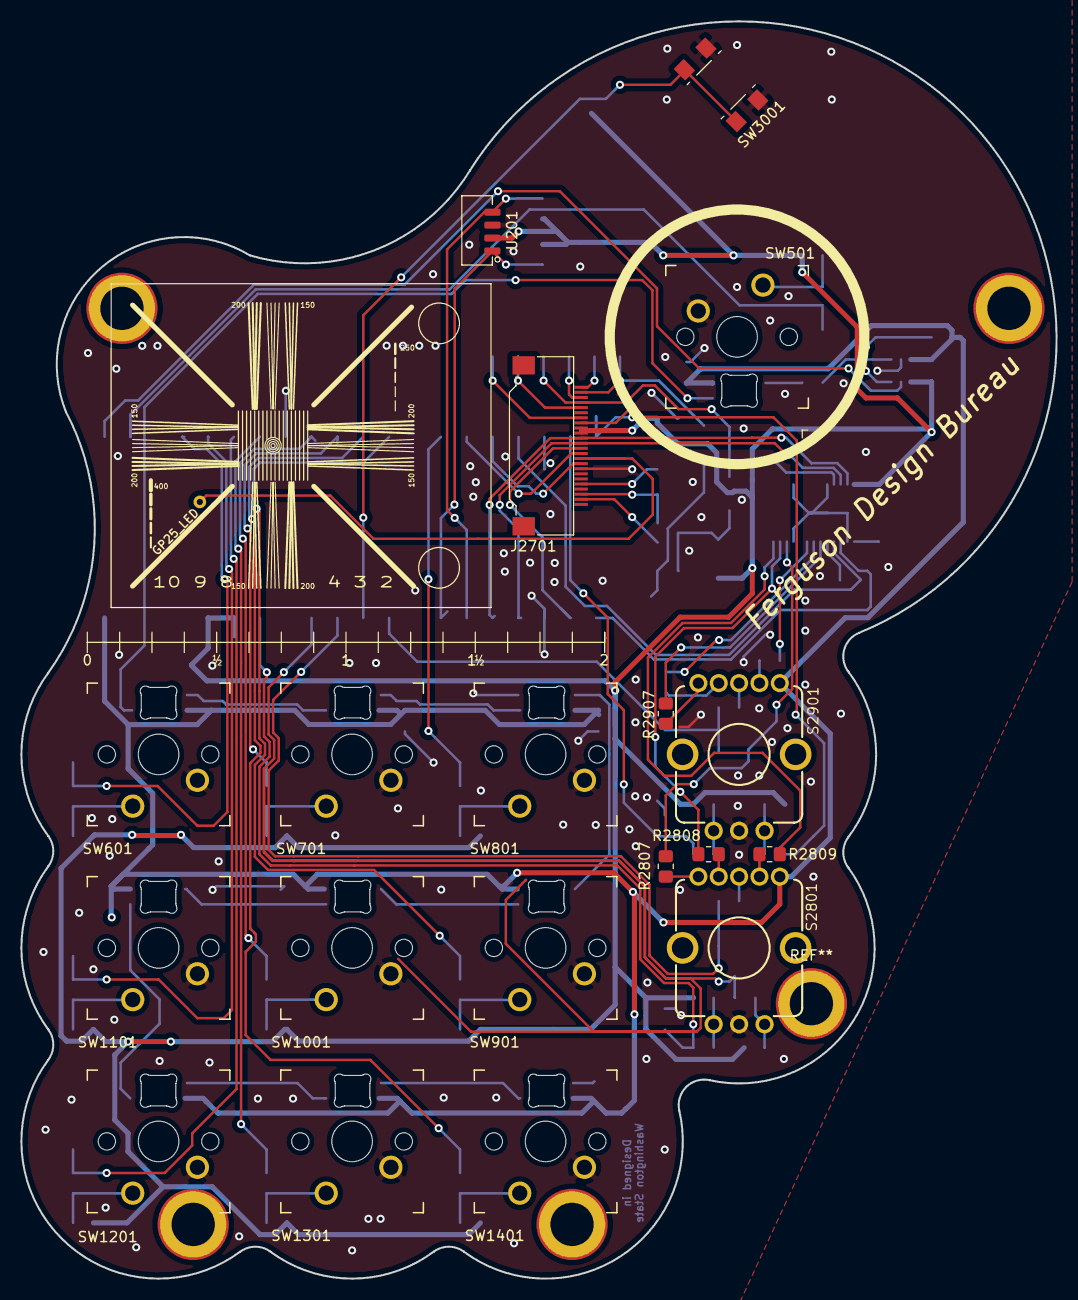
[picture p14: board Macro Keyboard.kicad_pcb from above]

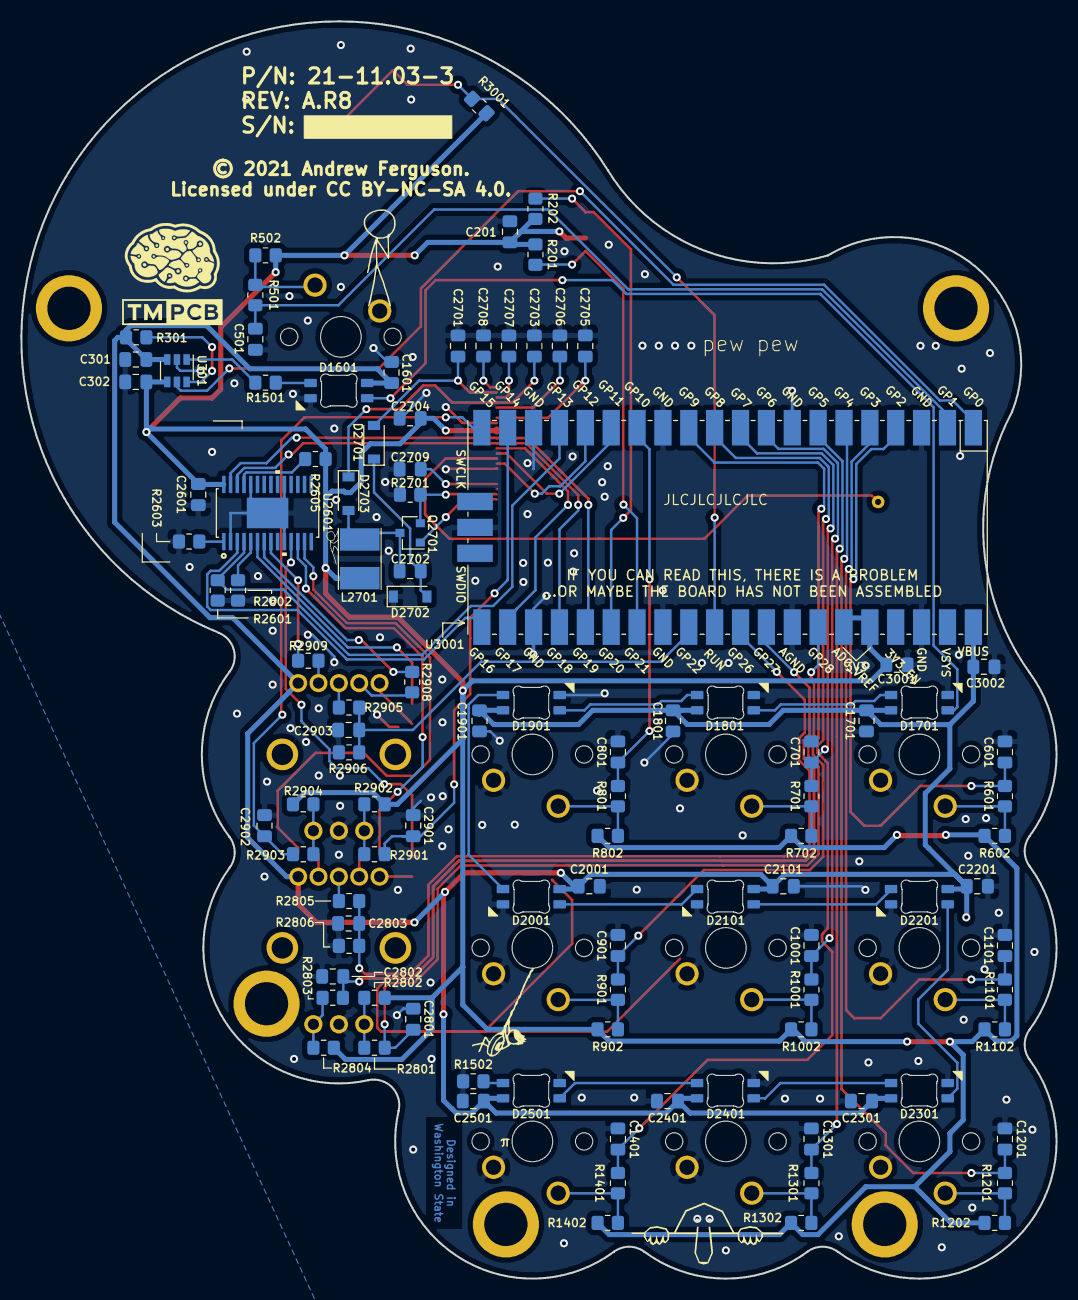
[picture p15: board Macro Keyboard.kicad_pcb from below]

Board: 2 copper layers, 101.6 x 123.4 mm, 129 parts (94 on the bottom side), 86 nets.

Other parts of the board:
DS**: e-paper_E2154FS091
Ref**: Val**; TMPCB Logo bottom silk 10mm
svg2mod: G***; kilroy
svg2mod#2: G***; xkcd-swing
svg2mod#3: G***; xkcd-climb
svg2mod#4: G***; xkcd

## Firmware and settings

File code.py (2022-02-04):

# SPDX-FileCopyrightText: 2022 Andrew Ferguson
#
# SPDX-License-Identifier: MIT
# pylint:disable=line-too-long


# Based on https://github.com/TeachMePCB/MacroKeypad/blob/main/Source/code.py

import time
import busio
import board
import displayio
import rotaryio
import digitalio
import neopixel
from digitalio import DigitalInOut, Direction, Pull
import usb_hid
from adafruit_hid.keyboard import Keyboard
from adafruit_hid.keycode import Keycode
from adafruit_hid.consumer_control import ConsumerControl
from adafruit_hid.consumer_control_code import ConsumerControlCode
from adafruit_led_animation.animation.blink import Blink
from adafruit_led_animation.animation.pulse import Pulse
from adafruit_led_animation.animation.rainbow import Rainbow
from adafruit_led_animation.animation.rainbowchase import RainbowChase
from adafruit_led_animation.animation.rainbowcomet import RainbowComet
from adafruit_led_animation.animation.rainbowsparkle import RainbowSparkle
from adafruit_led_animation import color
from adafruit_debouncer import Debouncer
from lib.fergcorp_pca9745b import PCA9745B
import adafruit_veml7700
from lib.fergcorp_pdispectra import PDISpectra
import random
import terminalio
from adafruit_display_text import label
from adafruit_button import Button

SWITCHES = [0, 1, 2, 3, 4, 5, 6, 7, 8, 9, 10, 11]
PIN_SETUP = [0, 1, 2, 3, 4, 5, 6, 7, 8, 9, 10, 11]

BLACK = 0x000000
WHITE = 0xFFFFFF
RED = 0xFF0000

ENABLE_EPAPER = True


class Macrokeypad:
    # State list
    STATE_INIT = 0
    STATE_KEYPAD = 1
    STATE_ADMIN = 2
    STATE_TEACHMEPCB = 4
    STATE_QR = 6
    STATE_GAME = 8

    NEOPIXEL = 1
    ROTARY_RGB = 2

    # Key type (determine what type of command is used)
    MEDIA = 1
    KEY = 2

    # list of pins to use (skipping GP15 on Pico because it's funky)
    PINS = [
        board.GP1,  # E-Button
        board.GP2,  # Button 1
        board.GP7,  # Button 2
        board.GP10,  # Button 3
        board.GP3,  # Button 4
        board.GP6,  # Button 5
        board.GP9,  # Button 6
        board.GP4,  # Button 7
        board.GP5,  # Button 8
        board.GP8,  # Button 9
        board.GP22,  # Top Rotary
        board.GP26,  # Bottom Rotary
    ]

    BUTTON_TO_LIGHT_ID = {
        0: 0,
        1: 1,
        2: 2,
        3: 3,
        4: 6,
        5: 5,
        6: 4,
        7: 7,
        8: 8,
        9: 9,
        10: 0,  # LED Group 0 of PCA9745B
        11: 1,  # LED Group 1 of PCA9745B
    }

    def __init__(self):
        self.state = self.STATE_INIT
        self.keymap = None
        self.kbd = Keyboard(usb_hid.devices)
        self.cc = ConsumerControl(usb_hid.devices)
        self.switches = {}

        self.encoder_top = self.encoder_top_position_last = None
        self.encoder_bottom = self.encoder_bottom_position_last = None

        displayio.release_displays()

        self.neopixels = self.init_neopixels(num_neopixels=10, brightness_step=50)

        self.load_keymap()

        self.init_rotary_encoders()
        self.spi_bus = self.init_spi()
        if ENABLE_EPAPER:
            self.display = self.init_epaper(self.spi_bus)
        else:
            # Prevents the epaper from thinking it's receiving commands when it's not under SPI control
            eink_driver_cs = digitalio.DigitalInOut(board.GP17)
            eink_driver_cs.direction = Direction.OUTPUT
            eink_driver_cs.value = True
        self.led = self.init_rotary_encoder_lights(self.spi_bus)
        self.init_tenkey()
        self.veml = self.init_veml()
        self.veml.light_gain = self.veml.ALS_GAIN_2

    def init_spi(self):
        return busio.SPI(clock=board.GP18, MOSI=board.GP19, MISO=board.GP16)

    def init_veml(self):
        i2c = busio.I2C(scl=board.GP21, sda=board.GP20)

        return adafruit_veml7700.VEML7700(i2c)

    def init_epaper(self, spi_bus) -> PDISpectra:

        displayio.release_displays()

        eink_driver_cs = board.GP17
        eink_driver_d_c = board.GP12
        eink_driver_busy = board.GP11
        eink_driver_res = board.LED

        display_bus = displayio.FourWire(
            spi_bus,
            command=eink_driver_d_c,
            chip_select=eink_driver_cs,
            reset=eink_driver_res,
        )

        display = PDISpectra(
            display_bus,
            height=152,
            width=152,
            rotation=90,
            busy_pin=eink_driver_busy,
            swap_rams=False,
            seconds_per_frame=30.0,
        )

        return display

    def setup_button(self, pin: board, pull_up: bool = True):
        this_pin = DigitalInOut(pin)
        this_pin.direction = Direction.INPUT
        if pull_up:
            this_pin.pull = Pull.UP
        else:
            this_pin.pull = Pull.DOWN
        return Debouncer(this_pin)

    def setup_encoder(
        self, pin_a: board, pin_b: board
    ) -> (rotaryio.IncrementalEncoder, rotaryio.IncrementalEncoder.position):
        encoder = rotaryio.IncrementalEncoder(pin_a, pin_b, divisor=4)
        position_last = encoder.position
        return encoder, position_last

    def init_tenkey(self):
        for i in range(10):
            self.switches[i] = self.setup_button(self.PINS[i])

    def init_rotary_encoders(self):

        self.switches[10] = self.setup_button(board.GP22, pull_up=False)
        self.switches[11] = self.setup_button(board.GP26, pull_up=False)

        self.encoder_top, self.encoder_top_position_last = self.setup_encoder(
            board.GP14, board.GP15
        )
        self.encoder_bottom, self.encoder_bottom_position_last = self.setup_encoder(
            board.GP28, board.GP27
        )

    def init_neopixels(self, num_neopixels, brightness_step):

        neopixels = neopixel.NeoPixel(board.GP0, num_neopixels, auto_write=True)
        pixel_brightness = brightness_step / 2
        neopixels.brightness = float(pixel_brightness) / brightness_step

        return neopixels

    def init_rotary_encoder_lights(self, spi_bus: busio.SPI) -> PCA9745B:
        # PCA9745B RGB LED Driver Setup
        led_driver_cs = digitalio.DigitalInOut(board.GP13)
        led_driver_cs.direction = Direction.OUTPUT
        led = PCA9745B(spi_bus, led_driver_cs, debug=False)

        led.reset()
        led.clear()

        led.set_gain_all(0x8)
        led.set_led_mode_by_group(0, 0x00)
        led.set_led_mode_by_group(1, 0x00)

        return led

    def load_keymap(self, map=1):
        # key type, keycode, normal color, color when pushed
        if map == 1:
            self.keymap = {
                (1): (
                    self.KEY,
                    [Keycode.OPTION, Keycode.SHIFT, Keycode.MINUS],
                    self.NEOPIXEL,
                    color.CYAN,
                    color.RED,
                ),
                # EM Dash
                (2): (
                    self.KEY,
                    [Keycode.OPTION, Keycode.MINUS],
                    self.NEOPIXEL,
                    color.AQUA,
                    color.JADE,
                ),  # EN Dash
                (3): (
                    self.KEY,
                    [Keycode.OPTION, Keycode.TWO],
                    self.NEOPIXEL,
                    color.BLUE,
                    color.YELLOW,
                ),  # ™
                (4): (
                    self.KEY,
                    [Keycode.COMMAND, Keycode.SHIFT, Keycode.THREE],
                    self.NEOPIXEL,
                    color.PINK,
                    color.GOLD,
                ),
                # Screenshot entire screen
                (5): (
                    self.KEY,
                    [Keycode.COMMAND, Keycode.SHIFT, Keycode.FOUR],
                    self.NEOPIXEL,
                    color.MAGENTA,
                    color.GREEN,
                ),
                # Screenshot selection
                (6): (
                    self.KEY,
                    [Keycode.F11],
                    self.NEOPIXEL,
                    color.OLD_LACE,
                    color.PURPLE,
                ),  # Show Desktop
                (7): (
                    self.KEY,
                    [Keycode.COMMAND, Keycode.X],
                    self.NEOPIXEL,
                    color.RED,
                    color.CYAN,
                ),  # CUT
                (8): (
                    self.KEY,
                    [Keycode.COMMAND, Keycode.C],
                    self.NEOPIXEL,
                    color.AMBER,
                    color.AQUA,
                ),  # COPY
                (9): (
                    self.KEY,
                    [Keycode.COMMAND, Keycode.V],
                    self.NEOPIXEL,
                    color.YELLOW,
                    color.BLUE,
                ),  # PASTE
                (0): (
                    self.KEY,
                    [Keycode.LEFT_CONTROL, Keycode.COMMAND, Keycode.Q],
                    self.NEOPIXEL,
                    color.WHITE,
                    color.RED,
                ),
                # Lock screen
                (10): (
                    self.MEDIA,
                    [Keycode.CAPS_LOCK],
                    self.ROTARY_RGB,
                    color.RED,
                    color.GREEN,
                ),  # Mute
                (11): (
                    self.MEDIA,
                    [ConsumerControlCode.MUTE],
                    self.ROTARY_RGB,
                    color.GREEN,
                    color.RED,
                ),  # Mute
            }
        elif map == 2:
            self.keymap = {
                (1): (
                    self.KEY,
                    [Keycode.OPTION, Keycode.SHIFT, Keycode.MINUS],
                    self.NEOPIXEL,
                    color.CYAN,
                    color.RED,
                ),
                # EM Dash
                (2): (
                    self.KEY,
                    [Keycode.OPTION, Keycode.MINUS],
                    self.NEOPIXEL,
                    color.AQUA,
                    color.JADE,
                ),  # EN Dash
                (3): (
                    self.KEY,
                    [Keycode.OPTION, Keycode.TWO],
                    self.NEOPIXEL,
                    color.BLUE,
                    color.YELLOW,
                ),  # ™
                (4): (
                    self.KEY,
                    [Keycode.COMMAND, Keycode.SHIFT, Keycode.THREE],
                    self.NEOPIXEL,
                    color.PINK,
                    color.GOLD,
                ),
                # Screenshot entire screen
                (5): (
                    self.KEY,
                    [Keycode.COMMAND, Keycode.SHIFT, Keycode.FOUR],
                    self.NEOPIXEL,
                    color.MAGENTA,
                    color.GREEN,
                ),
                # Screenshot selection
                (6): (
                    self.KEY,
                    [Keycode.F11],
                    self.NEOPIXEL,
                    color.OLD_LACE,
                    color.PURPLE,
                ),  # Show Desktop
                (7): (
                    self.KEY,
                    [Keycode.COMMAND, Keycode.X],
                    self.NEOPIXEL,
                    color.RED,
                    color.CYAN,
                ),  # CUT
                (8): (
                    self.KEY,
                    [Keycode.COMMAND, Keycode.C],
                    self.NEOPIXEL,
                    color.AMBER,
                    color.AQUA,
                ),  # COPY
                (9): (
                    self.KEY,
                    [Keycode.COMMAND, Keycode.V],
                    self.NEOPIXEL,
                    color.YELLOW,
                    color.BLUE,
                ),  # PASTE
                (0): (
                    self.KEY,
                    [Keycode.LEFT_CONTROL, Keycode.COMMAND, Keycode.Q],
                    self.NEOPIXEL,
                    color.WHITE,
                    color.RED,
                ),
                # Lock screen
                (10): (
                    self.MEDIA,
                    [Keycode.CAPS_LOCK],
                    self.ROTARY_RGB,
                    color.RED,
                    color.GREEN,
                ),  # Mute
                (11): (
                    self.MEDIA,
                    [ConsumerControlCode.MUTE],
                    self.ROTARY_RGB,
                    color.GREEN,
                    color.RED,
                ),  # Mute
            }

    def update_light_button(self, button, state=None, is_neopixel=True):
        btn = self.keymap[button]
        if btn[2] is self.NEOPIXEL:
            if state == 0:
                self.neopixels[self.BUTTON_TO_LIGHT_ID[button]] = (
                    btn[3][0],  # Red
                    btn[3][1],  # Green
                    btn[3][2],  # Blue
                )
            elif state == 1:
                self.neopixels[self.BUTTON_TO_LIGHT_ID[button]] = (
                    btn[4][0],  # Red
                    btn[4][1],  # Green
                    btn[4][2],  # Blue
                )
            else:
                rnd_color = random.choice(color.RAINBOW)
                self.neopixels[self.BUTTON_TO_LIGHT_ID[button]] = rnd_color
        elif btn[2] is self.ROTARY_RGB:
            # Because I routed the PCB wrong...BGR instead of RGB
            if self.BUTTON_TO_LIGHT_ID[button] == 0:
                if state == 0:
                    self.led.set_led_by_group(0, btn[3][0], btn[3][1], btn[3][2])
                elif state == 1:
                    self.led.set_led_by_group(0, btn[4][0], btn[4][1], btn[4][2])
                else:
                    self.led.set_led_by_group(0, *random.choice(color.RAINBOW))
            elif (
                self.BUTTON_TO_LIGHT_ID[button] == 1
            ):  # Because I routed the PCB wrong...BGR instead of RGB
                if state == 0:
                    self.led.set_led_by_group(1, btn[3][2], btn[3][1], btn[3][0])
                elif state == 1:
                    self.led.set_led_by_group(1, btn[4][2], btn[4][1], btn[4][0])
                else:
                    self.led.set_led_by_group(1, *random.choice(color.RAINBOW))

    def update_encoder(
        self,
        encoder: rotaryio.IncrementalEncoder,
        last_position: rotaryio.IncrementalEncoder.position,
        positive_action=None,
        negative_action=None,
    ):
        current_position = encoder.position
        position_change = current_position - last_position
        if position_change > 0:
            for _ in range(position_change):
                if self.neopixels.brightness < 1.0:
                    self.neopixels.brightness = (
                        self.neopixels.brightness + 0.1
                    )  # (1 / 255)
                    if positive_action is not None:
                        self.cc.send(positive_action)
        elif position_change < 0:
            for _ in range(-position_change):
                if self.neopixels.brightness > 0.0:
                    self.neopixels.brightness = (
                        self.neopixels.brightness - 0.1
                    )  # (1 / 255)
                    if negative_action is not None:
                        self.cc.send(negative_action)
        return current_position

    def run(self):
        if self.state is self.STATE_INIT:
            self.run_init()
        elif self.state is self.STATE_KEYPAD:
            self.run_keypad()
        elif self.state is self.STATE_ADMIN:
            self.run_admin()
        else:
            raise ValueError("Valid state not set.")

    def run_init(self):
        pass

    def run_keypad(self):
        if ENABLE_EPAPER:
            g = displayio.Group()
            with open("/macrokeyboard.bmp", "rb") as f:
                pic = displayio.OnDiskBitmap(f)
                # CircuitPython 6 & 7 compatible
                t = displayio.TileGrid(
                    pic,
                    pixel_shader=getattr(
                        pic, "pixel_shader", displayio.ColorConverter()
                    ),
                )
                # CircuitPython 7 compatible only
                # t = displayio.TileGrid(pic, pixel_shader=pic.pixel_shader)
                g.append(t)

                self.display.show(g)

                self.display_refresh()

        self.led.reset()
        self.led.set_gain_all(0x58)
        self.led.set_led_mode_by_group(0, 0x00)
        self.led.set_led_mode_by_group(1, 0x00)

        # Initialized colors of buttons
        for button in range(12):
            self.update_light_button(button, state=0)

        while self.state == self.STATE_KEYPAD:
            self.neopixels.brightness = (
                float(min(self.veml.light * 10, 65535) >> 8) / 255
            )
            self.led.set_global_dim(min(self.veml.light * 10, 65535) >> 8)
            for button in range(12):
                self.switches[button].update()
                if self.switches[button].fell:
                    self.update_light_button(button, state=1)
                    if self.keymap[button][0] == self.KEY:
                        self.kbd.send(*self.keymap[button][1])
                    elif self.keymap[button][0] == self.MEDIA:
                        self.cc.send(*self.keymap[button][1])
                    else:
                        raise ValueError("Unexpected button type")
                elif self.switches[button].rose:
                    self.update_light_button(button, state=0)
            if self.switches[10].fell:
                print("Button 10")
                self.state = self.STATE_ADMIN
                break

            self.encoder_top_position_last = self.update_encoder(
                encoder=self.encoder_top, last_position=self.encoder_top_position_last
            )
            self.encoder_bottom_position_last = self.update_encoder(
                encoder=self.encoder_bottom,
                last_position=self.encoder_bottom_position_last,
                positive_action=ConsumerControlCode.VOLUME_INCREMENT,
                negative_action=ConsumerControlCode.VOLUME_DECREMENT,
            )

    def run_game_tictactoe(self):

        g = displayio.Group()
        with open("/tictactoe.bmp", "rb") as f:
            pic = displayio.OnDiskBitmap(f)
            # CircuitPython 6 & 7 compatible
            t = displayio.TileGrid(
                pic,
                pixel_shader=getattr(pic, "pixel_shader", displayio.ColorConverter()),
            )
            # CircuitPython 7 compatible only
            # t = displayio.TileGrid(pic, pixel_shader=pic.pixel_shader)
            g.append(t)

            if ENABLE_EPAPER:
                self.display.show(g)
                self.display_refresh()

        # Based on https://www.freecodecamp.org/news/how-to-make-your-tic-tac-toe-game-unbeatable-by-using-the-minimax-algorithm-9d690bad4b37/
        def minimax(newBoard, player):

            huPlayer = "O"
            aiPlayer = "X"

            availSpots = []
            for i in range(len(newBoard)):
                if newBoard[i] != "X" and newBoard[i] != "O":
                    availSpots.append(i)

            # print("Availible spots: %s" % availSpots)
            if winning(newBoard, huPlayer):
                return {"score": -10}
            elif winning(newBoard, aiPlayer):
                return {"score": +10}
            elif len(availSpots) == 0:
                return {"score": 0}

            # an array to collect all the objects
            moves = []

            # loop through available spots
            for i in range(len(availSpots)):
                # create an object for each and store the index of that spot
                move = {}
                move["index"] = newBoard[availSpots[i]]

                # set the empty spot to the current player
                newBoard[availSpots[i]] = player

                # collect the score resulted from calling minimax
                #       on the opponent of the current player
                if player == aiPlayer:
                    result = minimax(newBoard, huPlayer)
                    move["score"] = result["score"]
                else:
                    result = minimax(newBoard, aiPlayer)
                    move["score"] = result["score"]

                # reset the spot to empty
                newBoard[availSpots[i]] = move["index"]

                moves.append(move)
            # if it is the computer's turn loop over the moves and choose the move with the highest score
            bestMove = None
            if player == aiPlayer:
                bestScore = -10000
                for i in range(len(moves)):
                    if moves[i]["score"] > bestScore:
                        bestScore = moves[i]["score"]
                        bestMove = i
            # else loop over the moves and choose the move with the lowest score
            else:
                bestScore = +10000
                for i in range(len(moves)):
                    if moves[i]["score"] < bestScore:
                        bestScore = moves[i]["score"]
                        bestMove = i

            return moves[bestMove]
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

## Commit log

2021-11-27 Intial commit
    [10GroupSwitch.sch, Debounce.sch, LED10.sch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]
2021-11-27 Added PCA9745B16B. Updated schematic. ERC Passes.
    [Macro Keyboard.sch, NeoLED.sch, Pico.sch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]
2021-11-27 fixed broken schematics becuase of deleted rescue files. ECA passes.
    [NeoLED.sch, Pico.sch]
2021-11-27 initial layout
    [LED10.sch, LightSensor.sch, NeoLED.sch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]
2021-11-29 Switch NeoPixel to SK6812MINI-E
    [Macro Keyboard.kicad_pcb, NeoLED.sch]
2021-11-29 design checkpoint
    [Macro Keyboard.kicad_pcb, Macro Keyboard.sch, Outline.FCStd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]
2021-11-30 Starting routing
    [10GroupSwitch.sch, LED10.sch, LevelConverter.sch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]
2021-12-01 Layout completed. Design check passes.
    [10GroupSwitch.sch, LED10.sch, LevelConverter.sch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]
2021-12-04 Moved everything to the back that I wanted. Added fun things :)
    [Asset 1.dxf, Asset-1.dxf, Macro Keyboard.kicad_pcb]
2021-12-05 Updated silkscreen outlines. Added epaper cad part.
    [Macro Keyboard.kicad_pcb, SK6812E-Sketch.dxf, SK6812E.FCStd]
2021-12-05 don't track gerber exports
2021-12-06 Add Solder Mask Clearance
    [Macro Keyboard.kicad_pcb]
2021-12-06 Move D2903 to allow for extra clearance
    [Macro Keyboard.kicad_pcb]
2021-12-06 Update GND connection on J2901 to remove sliver
    [Macro Keyboard.kicad_pcb]
2021-12-06 Updated several part orientations to eliminate minimuim clearance issues.
    [Macro Keyboard.kicad_pcb]
2021-12-06 Updated routing to eliminate minimuim clearance issues.
    [Macro Keyboard.kicad_pcb]
2021-12-06 Added labels
    [Macro Keyboard.kicad_pcb, Macro Keyboard.sch]
2021-12-07 Add net labels and update PCB
    [NeoLED.sch, Pico.sch, Switch.sch]
2021-12-07 Re-arrange pins and cleanup routing
    [Macro Keyboard.kicad_pcb, Macro Keyboard.sch, Switch.sch]
2021-12-07 Set all B.SilkS references to 0.8mm height and width
    [Macro Keyboard.kicad_pcb]
2021-12-07 Routing tweaks
    [Macro Keyboard.kicad_pcb]
2021-12-07 Tweak trace routings
    [Macro Keyboard.kicad_pcb]
2021-12-11 Flipped pins on J2901 to be 24-1 instead of 1-24
    [Macro Keyboard.kicad_pcb, Pico.sch]
2021-12-13 Change J2901 to Amphenon connector
    [Macro Keyboard.kicad_pcb, eInkDisplay.sch]
2021-12-13 Added estop stp and Marks comments from DFM check
    [Macro Keyboard.kicad_pcb]
2021-12-13 Add JLC P/N locator text
    [Macro Keyboard.kicad_pcb]
2021-12-13 singular e-stop cad file
2022-01-06 Fix design error in PI4ULS5V201TAEX. Reset and reassigned all annotations.
    [LED10.sch, LevelConverter.sch, LightSensor.sch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]
2022-01-07 Remove resistor for SPI MOSI, MISO, and CS for LED Driver
    [Macro Keyboard.kicad_pcb, RGBDrvier.sch, RotaryEncoder.sch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]
2022-01-09 Fixed wiring for rotary encoder 2. R and B pins were swapped.
    [Macro Keyboard.kicad_pcb, Macro Keyboard.sch, Switch.sch]
2022-01-12 Assignments for Pico GPIO 11 and 12 were flipped. Fixed.
    [Macro Keyboard.kicad_pcb, Pico.sch]
2022-01-19 R2701 should be 0.47 ohm...not 470 ohm
    [eInkDisplay.sch]
2022-01-28 Updated so that eink reset pin is shared with GP04. Not ideal, but should work.
    [Macro Keyboard.kicad_pcb, Macro Keyboard.sch, eInkDisplay.sch]
2022-02-01 Checkpoint for buttons vs labels
2022-02-02 Updated Switch to use Bournes P/N PEL12T-4225S-S1024, Update Connector to use Amphenol F31L-1A7H1-11024
    [Macro Keyboard.kicad_pcb, RotaryEncoder.sch, eInkDisplay.sch]
2022-02-02 Use GP25_LED for ePaper RESET
    Note: This replaces R6/196a722 in its entirety.
    IS: J2901 (Connector for epaper) Pin 10 (Reset) connected to +3.3V via R2902 (100k ohm)
    SHOULD BE: J2901 Pin 10 connected to U2801 Pin 48 (GPIO25_LED aka TP5)
    [Macro Keyboard.csv, Macro Keyboard.kicad_pcb, Macro Keyboard.sch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]
2022-02-03 Move files to hardware subfolder
    [10GroupSwitch.sch, Asset 1.dxf, Asset-1.dxf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]
2022-02-04 Fix logic bug for game. Set starting state to be admin screen.
    [code.py]

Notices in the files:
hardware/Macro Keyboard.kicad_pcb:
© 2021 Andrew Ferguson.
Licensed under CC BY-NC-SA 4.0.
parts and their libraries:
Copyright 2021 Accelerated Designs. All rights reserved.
